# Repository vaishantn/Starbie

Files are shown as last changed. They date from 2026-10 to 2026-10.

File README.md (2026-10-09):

# Starbie ⭐

**Starbie** is a tiny, interactive motion-controlled digital pet—think of a custom-built, hardware-hackable desktop Tamagotchi! Designed from scratch as a custom PCB, Starbie brings a virtual pet to life using an embedded microcontroller, a crisp OLED display, environmental sensors, tilt detection, and tactile mechanical keyboard switches.

---

## 📑 Table of Contents
- [Features](#-features)
- [Bill of Materials (BOM)](#-bill-of-materials-bom)
- [Hardware Architecture & Pinout](#️-hardware-architecture--pinout)
- [Getting Started & Firmware](#-getting-started--firmware-installation)
- [Project Schematics](#-project-schematics)
- [Built With](#-built-with)

---

## 🌟 Features

* **Motion & Tilt Detection:** Integrated MPU6050 6-axis accelerometer and gyroscope to track orientation, shakes, and tilts so you can interact with your pet physically.
* **Environment Tracking:** Built-in DHT11 sensor to monitor ambient temperature and humidity.
* **Tactile Mechanical Input:** Uses genuine Cherry MX mechanical switches for satisfying tactile user control.
* **Crisp Visuals:** Features a 0.96-inch OLED graphic display capable of rendering smooth animations and expressions for your digital pet.
* **Compact Microcontroller Core:** Powered by the versatile Seeed Studio XIAO ESP32-C3 for low-power operation, Wi-Fi capabilities, and compact integration.

---

## 📦 Bill of Materials (BOM)

| Part Name | Qty | Description |
| :--- | :---: | :--- |
| **Seeed Studio XIAO ESP32-C3** | 1 | Low-power RISC-V microcontroller with Wi-Fi/BLE |
| **0.96" OLED Graphic Display** | 1 | Monochrome display module (I2C/SPI) for character rendering |
| **MPU6050 Sensor Module** | 1 | 3-axis accelerometer & 3-axis gyroscope |
| **Cherry MX Silent Red Switch** | 2 | Mechanical keyboard switches for user input buttons |
| **DHT11 Sensor** | 1 | Digital temperature and humidity sensor |
| **10k Resistor** | 1 | Pull-up resistor for sensor stability |

---

## 🛠️ Hardware Architecture & Pinout

Starbie's schematic routes all peripherals directly to the XIAO ESP32-C3 breakout headers:
* **I2C Bus:** Shared between the MPU6050 motion sensor and the 0.96" OLED display.
* **GPIO Inputs:** Connected to the Cherry MX mechanical switches with internal pull-ups enabled.
* **Single-Wire Interface:** Dedicated pin for reading temperature and humidity data from the DHT11 module.

---

## 🚀 Getting Started & Firmware Installation

### Prerequisites
* [Arduino IDE](https://www.arduino.cc/en/software) installed on your machine.
* ESP32 board support packages added via the Arduino Board Manager.
* Required libraries installed:
  * `Adafruit_GFX` & `Adafruit_SSD1306` (for the OLED display)
  * `Adafruit_MPU6050` (for motion tracking)
  * `DHT sensor library` (for environmental data)

### Flashing the Firmware
1. Clone this repository or download the source files.
2. Open the `starbie.ino` file inside the Arduino IDE.
3. Select your board (`Seeed Studio XIAO_ESP32C3`) and the correct COM port from **Tools > Board**.
4. Click the **Upload** button to flash the code to your microcontroller.

---

## 📸 Project Schematics

<p align="center">
  Schematic View
</p>

<p align="center">
  PCB Layout View
</p>

---

## 🧰 Built With

* **KiCad** - Schematic capture, custom footprint creation, and PCB layout routing
* **Arduino IDE / C++** - Firmware development and sensor integration

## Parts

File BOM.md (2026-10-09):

# Starbie – bill of materials

<!-- Generated by Half Life from project cmuxftd3k013u01p9ftee1w4r. Edits here are overwritten on the next sync. -->
<!-- Generated: 2026-10-09T22:37:54.580Z -->

> [!NOTE]
> This parts list is mirrored from [Half Life](https://halflife.hackclub.com). Editing it here will not change the platform's copy, and the next sync overwrites this file.

| Week | Tier | Parts funding |
| --- | --- | --- |
| Week 1 | Tier 1 | $30.00 |

| Part | What it's for | Qty | Unit | Total | Vendor |
| --- | --- | --- | --- | --- | --- |
| [Seeed Studio XIAO ESP32-C3 module](https://www.robotshop.com/products/seeedstudio-xiao-esp32c3-tiny-mcu-w-wi-fi-ble) | microcontroller for the board | 1 | $5.95 | $5.95 | [Robot Shop](https://www.robotshop.com/products/seeedstudio-xiao-esp32c3-tiny-mcu-w-wi-fi-ble) |
| [0.96" OLED Graphic Display 128x64](https://www.displaymodule.com/products/0-96-inch-oled-graphic-display-128x64-with-spi-i2c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) | To show the character | 1 | $4.90 | $4.90 | [Display Module](https://www.displaymodule.com/products/0-96-inch-oled-graphic-display-128x64-with-spi-i2c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) |
| [MPU6050](https://shillehtek.com/products/shillehtek-mpu-6050-module-gy-521-module-unsoldered-version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) | To detect motion and tilt | 1 | $6.99 | $6.99 | [ShillehTek](https://shillehtek.com/products/shillehtek-mpu-6050-module-gy-521-module-unsoldered-version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) |
| [Cherry MX Linear Switch](https://www.digikey.com/en/products/detail/cherry-americas-llc/MX2A-71NN/21738450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) | To interact with starbie | 2 | $1.95 | $3.90 | [Digikey](https://www.digikey.com/en/products/detail/cherry-americas-llc/MX2A-71NN/21738450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) |
| [DHT11 Temperature-Humidity Sensor](https://www.waveshare.com/temperature-humidity-sensor.htm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) | To check temperature and humidity | 1 | $3.99 | $3.99 | [Waveshare](https://www.waveshare.com/temperature-humidity-sensor.htm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) |
| [10k resistor](https://www.digikey.com/en/products/detail/yageo/CFR-25JB-52-10K/338) | pull up resistor for DHT11 sensor | 1 | $0.20 | $0.20 | [Digikey](https://www.digikey.com/en/products/detail/yageo/CFR-25JB-52-10K/338) |
| **Parts subtotal** | — | — | — | **$25.93** | — |
| **Tax & shipping** | — | — | — | **$0.00** | — |
| **Total** | — | — | — | **$25.93** | — |

$4.07 left of the tier's funding.

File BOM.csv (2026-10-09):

# Starbie bill of materials
Week | Tier | Parts funding
--- | --- | ---
Week 1 | Tier 1 | $30.00
Part | What it's for | Qty | Unit | Total | Vendor
--- | --- | --- | --- | --- | ---
[Seeed Studio XIAO ESP32-C3 module](https://www.seeedstudio.com/Seeed-XIAO-ESP32C3-p-5431.html) | microcontroller for the board | 1 | $4.99 | $4.99 | [Seeed Studio](https://www.seeedstudio.com/Seeed-XIAO-ESP32C3-p-5431.html)
[0.96 OLED Graphic Display 128x64](https://www.displaymodule.com/products/0-96-inch-oled-graphic-display-128x64-with-spi-i2c" | To show the character | 1 | $4.90 | $4.90 | [Display Module](https://www.displaymodule.com/products/0-96-inch-oled-graphic-display-128x64-with-spi-i2c
[MPU6050](https://shillehtek.com/products/shillehtek-mpu-6050-module-gy-521-module-unsoldered-version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 | To detect motion and tilt | 1 | $6.99 | $6.99 | [ShillehTek](https://shillehtek.com/products/shillehtek-mpu-6050-module-gy-521-module-unsoldered-version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
[Cherry MX Silent Red 45g Linear Switch](https://mechanicalkeyboards.com/products/cherry-mx-silent-red-45g-linear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 | To interact with starbie | 2 | $0.40 | $0.80 | [Mechanical Keyboards](https://mechanicalkeyboards.com/products/cherry-mx-silent-red-45g-linear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
[DHT11 Temperature-Humidity Sensor](https://www.waveshare.com/temperature-humidity-sensor.htm | To check temperature and humidity | 1 | $3.99 | $3.99 | [Waveshare](https://www.waveshare.com/temperature-humidity-sensor.htm
[10k resistor](https://www.digikey.com/en/products/detail/yageo/CFR-25JB-52-10K/338) | pull up resistor for DHT11 sensor | 1 | $0.20 | $0.20 | [Digikey](https://www.digikey.com/en/products/detail/yageo/CFR-25JB-52-10K/338)
**Parts subtotal** |  |  |  | $21.87
**Tax & shipping** |  |  |  | $0.00
**Total** |  |  |  | $21.87

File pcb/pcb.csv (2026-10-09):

Reference | Qty | Value | DNP | Exclude from BOM | Exclude from Board | Exclude from Simulation | Exclude from Position Files | Footprint | Datasheet
J1 | 1 | Conn_01x04_Pin |  |  |  |  | ${EXCLUDE_FROM_POS_FILES} | Imported Parts:Display_128x64_096_I2C
J2 | 1 | Conn_01x08_Pin |  |  |  |  | ${EXCLUDE_FROM_POS_FILES} | Connector_PinHeader_2.54mm:PinHeader_1x08_P2.54mm_Vertical
R1 | 1 | 10k |  |  |  |  | ${EXCLUDE_FROM_POS_FILES} | Resistor_THT:R_Axial_DIN0204_L3.6mm_D1.6mm_P7.62mm_Horizontal
SW1,SW2 | 2 | SW_Push |  |  |  |  | ${EXCLUDE_FROM_POS_FILES} | Button_Switch_Keyboard:SW_Cherry_MX_1.00u_PCB
U1 | 1 | XIAO-ESP32-C3-SMD |  |  |  |  | ${EXCLUDE_FROM_POS_FILES} | Seeed Studio XIAO Series Library:XIAO-ESP32-C3-SMD
U2 | 1 | DHT11 |  |  |  |  | ${EXCLUDE_FROM_POS_FILES} | Sensor:Aosong_DHT11_5.5x12.0_P2.54mm | http://akizukidenshi.com/download/ds/aosong/DHT11.pdf

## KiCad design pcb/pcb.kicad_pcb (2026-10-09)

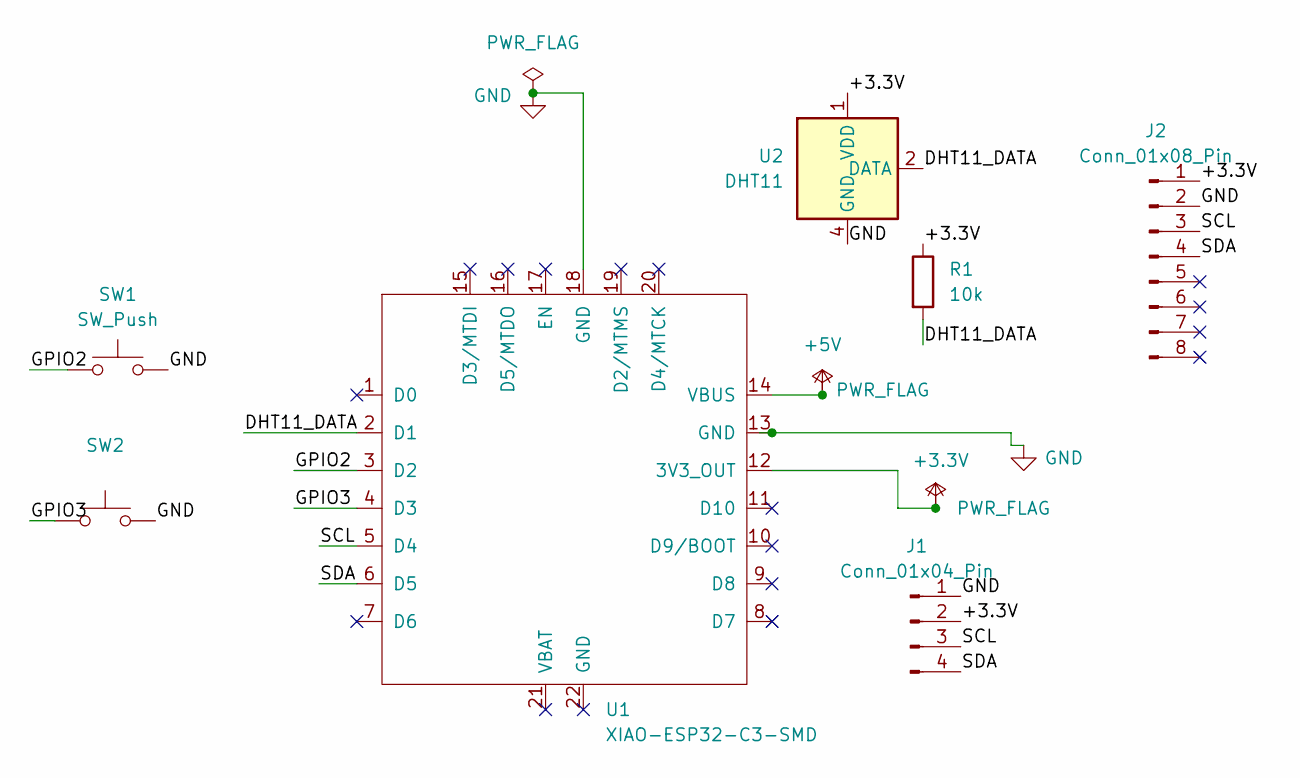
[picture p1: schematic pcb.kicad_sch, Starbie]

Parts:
J1: Conn_01x04_Pin; Display_128x64_096_I2C
J2: Conn_01x08_Pin; PinHeader_1x08_P2.54mm_Vertical
R1: 10k; R_Axial_DIN0204_L3.6mm_D1.6mm_P7.62mm_Horizontal
SW1, SW2: SW_Push; SW_Cherry_MX_1.00u_PCB
U1: XIAO-ESP32-C3-SMD
U2: DHT11; Aosong_DHT11_5.5x12.0_P2.54mm

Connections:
+3.3V: J1.2, J2.1, R1.1, U1.12 (3V3_OUT), U2.1 (VDD)
+5V: U1.14 (VBUS)
/DHT11_DATA: R1.2, U1.2 (D1), U2.2 (DATA)
/GPIO2: SW1.1, U1.3 (D2)
/GPIO3: SW2.1, U1.4 (D3)
/SCL: J1.3, J2.3, U1.5 (D4)
/SDA: J1.4, J2.4, U1.6 (D5)
GND: J1.1, J2.2, SW1.2, SW2.2, U1.13 (GND), U1.18 (GND), U2.4 (GND)

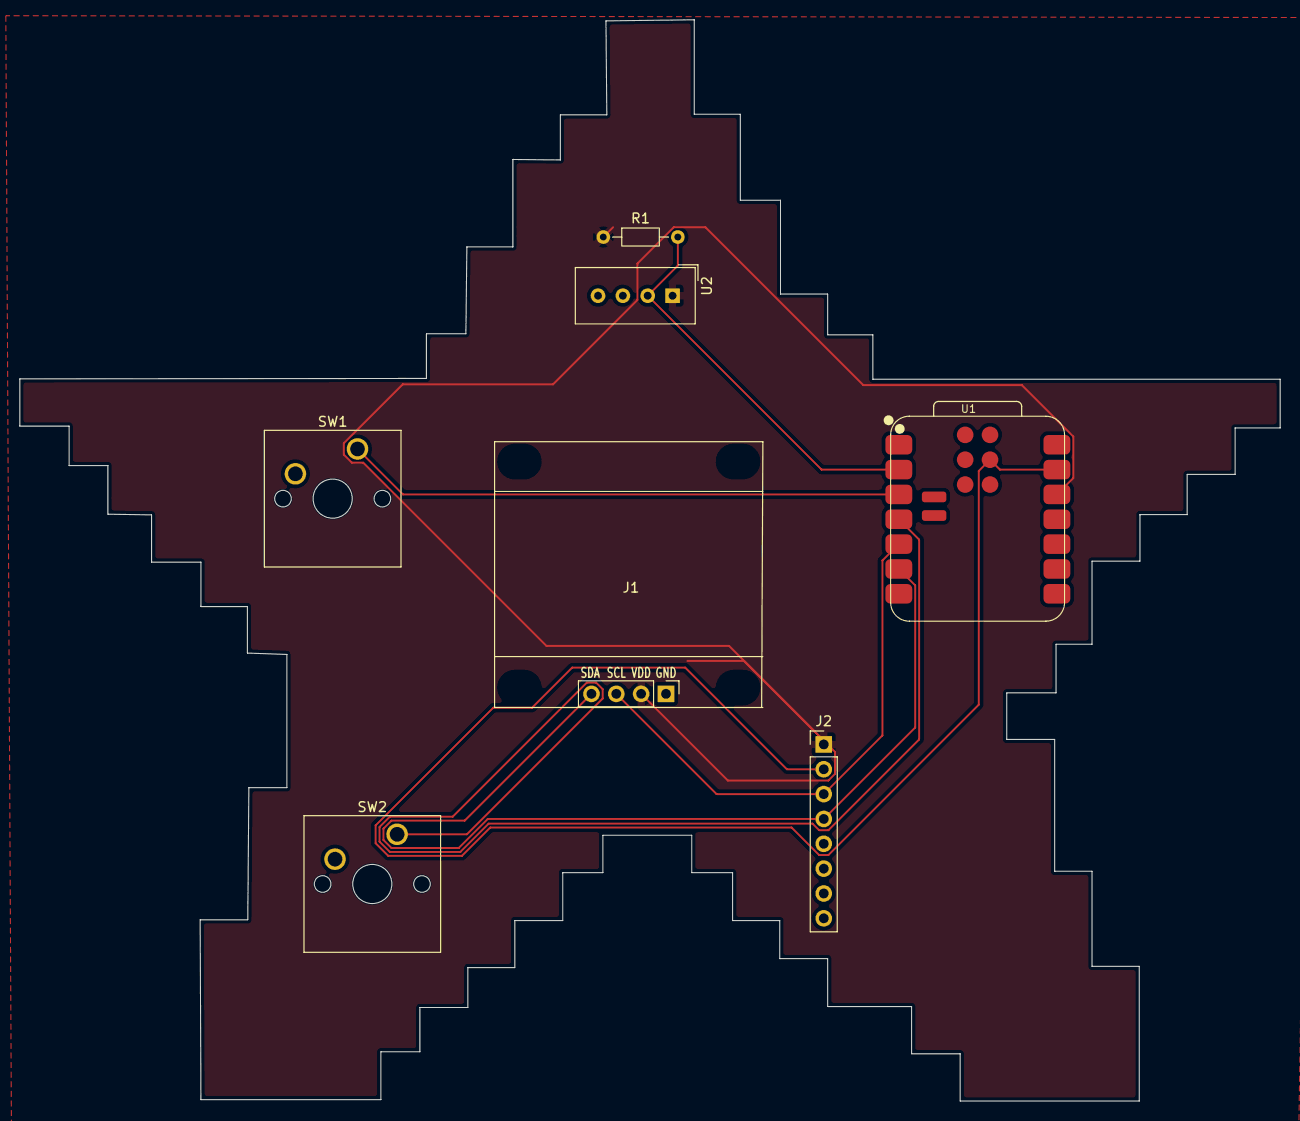
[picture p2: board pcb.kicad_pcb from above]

Board: 2 copper layers, 128.9 x 110.5 mm, 7 parts (0 on the bottom side), 7 nets.

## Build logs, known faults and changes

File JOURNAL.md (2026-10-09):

# Starbie – devlog

<!-- Generated by Half Life from project cmuxftd3k013u01p9ftee1w4r. Edits here are overwritten on the next sync. -->
<!-- Generated: 2026-10-09T22:26:31.207Z -->

> [!NOTE]
> This devlog is mirrored from [Half Life](https://halflife.hackclub.com). Editing it here will not change the platform's copy, and the next sync overwrites this file.

> A tiny motion-controlled digital pet, basically a desktop Tamagotchi. Totally not a Starboy.

| Week | Tier | Hours logged | Entries |
| --- | --- | --- | --- |
| Week 1 | Tier 1 | 11h | 8 |

## Contents

1. [2026-10-06 – Worked on the schematic in KiCad today! Grounded one side of the push button to GND and connected the signal pin directly to D0 on the XIAO ESP32-C3 for active-LOW input. Also wired up the power and g](#2026-10-06-worked-on-the-schematic-in-kicad-today-grounded-o)
2. [2026-10-07 – Finished drawing up the entire schematic in KiCad! All components are placed, connected, and verified. Next up is importing everything into the PCB editor to beautify the board layout—arranging the co](#2026-10-07-finished-drawing-up-the-entire-schematic-in-kicad)
3. [2026-10-08 – Today I continued cleaning up the schematic from yesterday. At first I thought I would just spend my time manually rerouting wires around the board to make it look neater. Instead, I learned how to us](#2026-10-08-today-i-continued-cleaning-up-the-schematic-from-)
4. [2026-10-08 – I started moving my finished schematic into the PCB layout! While I was doing this, I found a lot of errors because several of my parts didn't have the correct footprints assigned to them. I had to ch](#2026-10-08-i-started-moving-my-finished-schematic-into-the-p)
5. [2026-10-09 – I finished routing the pcb wiring. It took me so much time to get the custom boundary right because the first time it was too big, the second time it was too small, and the third time it was just righ](#2026-10-09-i-finished-routing-the-pcb-wiring-it-took-me-so-m)
6. [2026-10-09 – Spent this 2-hour session focusing on project documentation and component organization for Starbie. I put together a clear Bill of Materials (BOM) listing out all the necessary hardware like the micro](#2026-10-09-spent-this-2-hour-session-focusing-on-project-doc)
7. [2026-10-09 – Spent this 1-hour session cleaning up and refining the project repository for Starbie. I updated the README with comprehensive build details, organized all the exported Gerber (`.gbr`) layer files, jo](#2026-10-09-spent-this-1-hour-session-cleaning-up-and-refinin)
8. [2026-10-09 – Completely overhauled the project `README.md` for Starbie by introducing an intuitive Table of Contents, organizing a polished layout hierarchy, and refining both the Bill of Materials (BOM) and core](#2026-10-09-completely-overhauled-the-project-readmemd-for-st)

## Design

### 2026-10-06 – Worked on the schematic in KiCad today! Grounded one side of the push button to GND and connected the signal pin directly to D0 on the XIAO ESP32-C3 for active-LOW input. Also wired up the power and g

**1h**

Worked on the schematic in KiCad today! Grounded one side of the push button to GND and connected the signal pin directly to D0 on the XIAO ESP32-C3 for active-LOW input. Also wired up the power and ground paths across the component pins





### 2026-10-07 – Finished drawing up the entire schematic in KiCad! All components are placed, connected, and verified. Next up is importing everything into the PCB editor to beautify the board layout—arranging the co

**1h**

Finished drawing up the entire schematic in KiCad! All components are placed, connected, and verified. Next up is importing everything into the PCB editor to beautify the board layout—arranging the components neatly, adding custom graphics, and preparing for routing.





### 2026-10-08 – Today I continued cleaning up the schematic from yesterday. At first I thought I would just spend my time manually rerouting wires around the board to make it look neater. Instead, I learned how to us

**2h**

Today I continued cleaning up the schematic from yesterday. At first I thought I would just spend my time manually rerouting wires around the board to make it look neater. Instead, I learned how to use net labels to clean up the design. This makes the schematic look significantly more organized and much easier to read than having messy wires crossing each other all over the place!

This is before:


This is after:


### 2026-10-08 – I started moving my finished schematic into the PCB layout! While I was doing this, I found a lot of errors because several of my parts didn't have the correct footprints assigned to them. I had to ch

**1h**

I started moving my finished schematic into the PCB layout! While I was doing this, I found a lot of errors because several of my parts didn't have the correct footprints assigned to them. I had to check every part, figure out the errors, and assign the right footprints so everything would fit properly on the board.

From this:



To this:



### 2026-10-09 – I finished routing the pcb wiring. It took me so much time to get the custom boundary right because the first time it was too big, the second time it was too small, and the third time it was just righ

**3h**

I finished routing the pcb wiring. It took me so much time to get the custom boundary right because the first time it was too big, the second time it was too small, and the third time it was just right. Next I encountered a problem: I didn't assign the footprints correctly, so it took me time to fix it. Then the routing of wires took me time because I was trying to understand how to do it and I kept not having enough space, so I tweaked some copper zoning and now I have completed it.

Before:


After:




### 2026-10-09 – Spent this 2-hour session focusing on project documentation and component organization for Starbie. I put together a clear Bill of Materials (BOM) listing out all the necessary hardware like the micro

**2h**

Spent this 2-hour session focusing on project documentation and component organization for Starbie. I put together a clear Bill of Materials (BOM) listing out all the necessary hardware like the microcontroller, sensors, and mechanical switches, and to find the perfect vendor. I also wrote and refined the project README to properly document the build.

BOM:



Readme:





### 2026-10-09 – Spent this 1-hour session cleaning up and refining the project repository for Starbie. I updated the README with comprehensive build details, organized all the exported Gerber (`.gbr`) layer files, jo

**0.5h**

Spent this 1-hour session cleaning up and refining the project repository for Starbie. I updated the README with comprehensive build details, organized all the exported Gerber (`.gbr`) layer files, job files, and drill files (`.drl`) into a clean directory structure, and prepared everything for final production.

Added this to Readme:



Added gerbers:



### 2026-10-09 – Completely overhauled the project `README.md` for Starbie by introducing an intuitive Table of Contents, organizing a polished layout hierarchy, and refining both the Bill of Materials (BOM) and core

**0.5h**

Completely overhauled the project `README.md` for Starbie by introducing an intuitive Table of Contents, organizing a polished layout hierarchy, and refining both the Bill of Materials (BOM) and core feature sections to prep the custom PCB repo.







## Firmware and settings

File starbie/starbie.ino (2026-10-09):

#include <Wire.h>
#include <Adafruit_GFX.h>
#include <Adafruit_SSD1306.h>
#include <Adafruit_MPU6050.h>
#include <DHT.h>
#include <Preferences.h>
#include <math.h>

// =========================== BEGINNER SETTINGS ===========================
// Everything most builders will want to customize is in this one section.

// --- Your board's pins ----------------------------------------------------
// These are ESP32-C3 GPIO numbers, with the XIAO pin labels beside them.
const int I2C_SDA_PIN = 6;       // XIAO D4: OLED + MPU6050 SDA
const int I2C_SCL_PIN = 7;       // XIAO D5: OLED + MPU6050 SCL
const int DHT_PIN = 3;           // XIAO D1: DHT11 data
const int BUTTON_ONE_PIN = 4;    // XIAO D2: opens/confirms the radial menu
const int BUTTON_TWO_PIN = 5;    // XIAO D3: shows/hides stats

// Set this to false if your submission does not have a DHT11.
const bool USE_DHT11 = true;

// Most parts use these addresses. Only change them if an I2C scanner says
// your part is different (common OLED alternative: 0x3D).
const uint8_t OLED_ADDRESS = 0x3C;
const uint8_t MPU6050_ADDRESS = 0x68;

// --- Starting stats -------------------------------------------------------
// Stats are 0 to 100. They only change when you select an action or shake
// Starbie; nothing slowly drains while it sits on your desk.
const int STARTING_JOY = 70;
const int STARTING_ENERGY = 75;
const int STARTING_FULLNESS = 65;

// Set true, upload once, then set it back to false if you want a fresh pet.
const bool RESET_SAVED_PET_ON_BOOT = false;

// --- Radial menu ----------------------------------------------------------
// These four actions appear at TOP, RIGHT, BOTTOM, then LEFT in the menu.
// The last word controls the matching little visual reaction.
enum PetReaction {
  NAP_REACTION,
  JUMP_REACTION,
  HEART_REACTION,
  RUN_REACTION,
};

struct MenuItem {
  const char *label;
  int joyChange;
  int energyChange;
  int fullnessChange;
  PetReaction reaction;
};

const MenuItem MENU_ITEMS[] = {
  {"NAP",   1,  18, -4, NAP_REACTION},   // top: sleep and emit Zs
  {"PLAY", 12, -9, -5, RUN_REACTION},    // right: two fast laps + hearts
  {"FEED",  3,  2,  18, JUMP_REACTION},  // bottom: wiggle and jump
  {"PET",   7,  0,  0, HEART_REACTION},  // left: jump and emit hearts
};
const int MENU_ITEM_COUNT = sizeof(MENU_ITEMS) / sizeof(MENU_ITEMS[0]);

// --- Movement feel --------------------------------------------------------
// Bigger MENU_TILT_LIMIT makes the menu ball move less.
const float MENU_TILT_LIMIT = 6.0f;

// MPU6050 orientation: change these settings instead of rewiring your board.
// 1. If the sensor is turned 90 degrees, set SWAP_MPU_AXES to true.
// 2. If a direction feels backwards, change that direction from 1.0f to -1.0f.
const bool SWAP_MPU_AXES = false;
const float MENU_X_DIRECTION = 1.0f;
const float MENU_Y_DIRECTION = -1.0f;

// A small dead zone makes the ball rest in the center until the board is tilted.
const float MENU_CENTER_DEADZONE = 0.8f;
const float SHAKE_THRESHOLD = 7.0f;

// Shake is the only movement that has an effect outside the radial menu.
const int SHAKE_JOY_CHANGE = 5;
const int SHAKE_ENERGY_CHANGE = -2;
const int SHAKE_FULLNESS_CHANGE = -1;

// --- Your pet's bitmap and animation -------------------------------------
// This is a simplified 32 by 32, one-bit version of the supplied character.
// You can replace it with your own art later; keep these size values matched
// to the sprite array you paste in.
const int PET_SPRITE_WIDTH = 32;
const int PET_SPRITE_HEIGHT = 32;

// The pet wanders unless it is asleep. A non-nap action does a tiny shake,
// then a jump, except PLAY which runs two fast laps.
const uint16_t PET_WALK_PIXEL_MS = 70;
const uint16_t PET_PRE_JUMP_MS = 230;
const uint16_t PET_JUMP_MS = 430;
const int PET_JUMP_HEIGHT = 16;
const uint32_t NAP_DURATION_MS = 48000;  // 48 seconds: four times the old nap.
const uint16_t HEARTS_DURATION_MS = 1600;
const uint16_t PLAY_LAP_MS = 800;
const uint8_t PLAY_LAP_COUNT = 2;

// Each byte stores eight pixels, left to right. This sparse outline keeps the
// supplied creature readable on a tiny, one-bit OLED: head, eye, legs, tail,
// and a small flower-like ear accent all stay separate instead of becoming a blob.
const uint8_t PROGMEM PET_SPRITE[] = {
  0x00, 0x00, 0x00, 0x00,
  0x00, 0x00, 0x00, 0x00,
  0x00, 0x00, 0x00, 0x00,
  0x00, 0x00, 0x00, 0x00,
  0x00, 0x00, 0x00, 0x00,
  0x00, 0x00, 0x00, 0x00,
  0x00, 0x70, 0x0a, 0x00,
  0x00, 0xf8, 0x1f, 0x00,
  0x00, 0x8c, 0x3f, 0x80,
  0x00, 0x43, 0xff, 0x00,
  0x00, 0x43, 0xff, 0x00,
  0x00, 0x30, 0x7e, 0x00,
  0x00, 0x98, 0x01, 0x00,
  0x01, 0x98, 0x01, 0x80,
  0x03, 0x00, 0x10, 0xc0,
  0x03, 0x04, 0x00, 0xc0,
  0x01, 0x8b, 0x01, 0x80,
  0x01, 0xcb, 0x03, 0x80,
  0x03, 0xc0, 0x03, 0xc0,
  0x03, 0xc0, 0x03, 0xc0,
  0x01, 0xc0, 0x03, 0x80,
  0x01, 0x80, 0x01, 0x80,
  0x00, 0x60, 0x06, 0x00,
  0x00, 0x3f, 0xfc, 0x00,
  0x00, 0x7f, 0xfe, 0x00,
  0x00, 0x70, 0x0e, 0x00,
  0x00, 0x00, 0x00, 0x00,
  0x00, 0x00, 0x00, 0x00,
  0x00, 0x00, 0x00, 0x00,
  0x00, 0x00, 0x00, 0x00,
  0x00, 0x00, 0x00, 0x00,
  0x00, 0x00, 0x00, 0x00,
};
// ===========================================================================
// You can read below without needing to understand every line. The rest of
// the sketch handles buttons, sensors, drawing, and saving automatically.

const int SCREEN_WIDTH = 128;
const int SCREEN_HEIGHT = 64;
const int MENU_CENTER_X = 64;
const int MENU_CENTER_Y = 32;
const int MENU_ITEM_X[] = {64, 108, 64, 20};
const int MENU_ITEM_Y[] = {12, 32, 53, 32};
const int MENU_BALL_X_RANGE = 37;
const int MENU_BALL_Y_RANGE = 22;
const uint16_t BUTTON_DEBOUNCE_MS = 30;
const uint16_t MPU_READ_INTERVAL_MS = 30;
const uint16_t DHT_READ_INTERVAL_MS = 2200;
const uint16_t SHAKE_COOLDOWN_MS = 650;
const float STANDARD_GRAVITY = 9.80665f;

Adafruit_SSD1306 display(SCREEN_WIDTH, SCREEN_HEIGHT, &Wire, -1);
Adafruit_MPU6050 mpu;
DHT dht(DHT_PIN, DHT11);
Preferences preferences;

struct PetState {
  int joy;
  int energy;
  int fullness;
};

struct ButtonState {
  int pin;
  bool stableState;
  bool lastRawState;
  uint32_t lastChangedAt;
};

enum View {
  PET_VIEW,
  MENU_VIEW,
  STATS_VIEW,
};

PetState pet = {STARTING_JOY, STARTING_ENERGY, STARTING_FULLNESS};
ButtonState buttonOne = {BUTTON_ONE_PIN, HIGH, HIGH, 0};
ButtonState buttonTwo = {BUTTON_TWO_PIN, HIGH, HIGH, 0};
View currentView = PET_VIEW;

bool mpuFound = false;
bool dhtFound = false;
float accelerationX = 0.0f;
float accelerationY = 0.0f;
float accelerationZ = STANDARD_GRAVITY;
float temperatureC = NAN;
float humidity = NAN;
float menuBallX = MENU_CENTER_X;
float menuBallY = MENU_CENTER_Y;
float menuCenterAccelerationX = 0.0f;
float menuCenterAccelerationY = 0.0f;
int selectedMenuItem = -1;
uint32_t lastMpuReadAt = 0;
uint32_t lastDhtReadAt = 0;
uint32_t lastShakeAt = 0;
uint32_t shakeAnimationEndsAt = 0;
uint32_t petJumpStartedAt = 0;
uint32_t nappingUntil = 0;
uint32_t heartAnimationEndsAt = 0;
uint32_t playRunStartedAt = 0;
int nappingPetX = 0;

int petWalkingX(uint32_t now);

int keepInRange(int value, int smallest, int largest) {
  return constrain(value, smallest, largest);
}

void changePet(int joyChange, int energyChange, int fullnessChange) {
  pet.joy = keepInRange(pet.joy + joyChange, 0, 100);
  pet.energy = keepInRange(pet.energy + energyChange, 0, 100);
  pet.fullness = keepInRange(pet.fullness + fullnessChange, 0, 100);
}

void loadPet() {
  preferences.begin("starbie", false);
  if (RESET_SAVED_PET_ON_BOOT) {
    preferences.clear();
  }
  pet.joy = preferences.getInt("joy", STARTING_JOY);
  pet.energy = preferences.getInt("energy", STARTING_ENERGY);
  pet.fullness = preferences.getInt("full", STARTING_FULLNESS);
}

void savePet() {
  preferences.putInt("joy", pet.joy);
  preferences.putInt("energy", pet.energy);
  preferences.putInt("full", pet.fullness);
}

void setUpButton(ButtonState &button) {
  pinMode(button.pin, INPUT_PULLUP);
  button.stableState = digitalRead(button.pin);
  button.lastRawState = button.stableState;
  button.lastChangedAt = millis();
}

// Returns true exactly once for each press, even if the switch bounces.
bool wasPressed(ButtonState &button) {
  const bool rawState = digitalRead(button.pin);
  const uint32_t now = millis();

  if (rawState != button.lastRawState) {
    button.lastRawState = rawState;
    button.lastChangedAt = now;
  }

  if (rawState != button.stableState &&
      now - button.lastChangedAt >= BUTTON_DEBOUNCE_MS) {
    button.stableState = rawState;
    return button.stableState == LOW;
  }

  return false;
}

void updateMpu() {
  if (!mpuFound || millis() - lastMpuReadAt < MPU_READ_INTERVAL_MS) {
    return;
  }
  lastMpuReadAt = millis();

  sensors_event_t acceleration;
  sensors_event_t gyro;
  sensors_event_t sensorTemperature;
  mpu.getEvent(&acceleration, &gyro, &sensorTemperature);
  accelerationX = acceleration.acceleration.x;
  accelerationY = acceleration.acceleration.y;
  accelerationZ = acceleration.acceleration.z;
}

void updateDht() {
  if (!dhtFound || millis() - lastDhtReadAt < DHT_READ_INTERVAL_MS) {
    return;
  }
  lastDhtReadAt = millis();

  const float newHumidity = dht.readHumidity();
  const float newTemperatureC = dht.readTemperature();
  if (!isnan(newHumidity)) {
    humidity = newHumidity;
  }
  if (!isnan(newTemperatureC)) {
    temperatureC = newTemperatureC;
  }
}

int petWalkingX(uint32_t now) {
  const int farthestX = SCREEN_WIDTH - PET_SPRITE_WIDTH;
  const uint32_t roundTrip = static_cast<uint32_t>(farthestX) * 2;
  const uint32_t step = (now / PET_WALK_PIXEL_MS) % roundTrip;
  return step <= farthestX ? step : roundTrip - step;
}

uint32_t playRunDuration() {
  return static_cast<uint32_t>(PLAY_LAP_MS) * PLAY_LAP_COUNT;
}

bool isNapping() {
  return nappingUntil != 0 && millis() < nappingUntil;
}

bool isPlaying() {
  return playRunStartedAt != 0 && millis() - playRunStartedAt < playRunDuration();
}

int playRunX(uint32_t now) {
  const int farthestX = SCREEN_WIDTH - PET_SPRITE_WIDTH;
  const uint32_t lapAge = (now - playRunStartedAt) % PLAY_LAP_MS;
  const float progress = static_cast<float>(lapAge) / PLAY_LAP_MS;
  return progress < 0.5f ? static_cast<int>(progress * 2.0f * farthestX)
                         : static_cast<int>((1.0f - progress) * 2.0f * farthestX);
}

void updatePetTimers() {
  if (nappingUntil != 0 && !isNapping()) {
    nappingUntil = 0;  // The pet wakes naturally when its nap time is over.
  }
  if (playRunStartedAt != 0 && !isPlaying()) {
    playRunStartedAt = 0;  // PLAY is exactly two left-to-right-to-left laps.
  }
}

// While the menu is open, the MPU6050 acts like a tiny air mouse. The position
// at the instant Button 1 opens the menu becomes the center for that menu use.
void updateMenuBall() {
  float xTilt = accelerationX - menuCenterAccelerationX;
  float yTilt = accelerationY - menuCenterAccelerationY;

  if (SWAP_MPU_AXES) {
    const float oldXTilt = xTilt;
    xTilt = yTilt;
    yTilt = oldXTilt;
  }
  xTilt = constrain(xTilt * MENU_X_DIRECTION, -MENU_TILT_LIMIT, MENU_TILT_LIMIT);
  yTilt = constrain(yTilt * MENU_Y_DIRECTION, -MENU_TILT_LIMIT, MENU_TILT_LIMIT);
  const float targetX = MENU_CENTER_X + (xTilt / MENU_TILT_LIMIT) * MENU_BALL_X_RANGE;
  const float targetY = MENU_CENTER_Y + (yTilt / MENU_TILT_LIMIT) * MENU_BALL_Y_RANGE;

  // This small amount of smoothing makes the ball feel less jittery.
  menuBallX += (targetX - menuBallX) * 0.20f;
  menuBallY += (targetY - menuBallY) * 0.20f;

  // The menu has four full sectors, not four tiny targets. Any tilt direction
  // past the center dead zone selects its matching top/right/bottom/left action.
  if (fabsf(xTilt) < MENU_CENTER_DEADZONE && fabsf(yTilt) < MENU_CENTER_DEADZONE) {
    selectedMenuItem = -1;
  } else if (fabsf(xTilt) > fabsf(yTilt)) {
    selectedMenuItem = xTilt > 0.0f ? 1 : 3;  // right or left
  } else {
    selectedMenuItem = yTilt > 0.0f ? 2 : 0;  // bottom or top
  }
}

void checkForShake() {
  if (!mpuFound || currentView != PET_VIEW) {
    return;
  }

  const float magnitude = sqrtf(accelerationX * accelerationX +
                                accelerationY * accelerationY +
                                accelerationZ * accelerationZ);
  const uint32_t now = millis();
  if (fabsf(magnitude - STANDARD_GRAVITY) >= SHAKE_THRESHOLD &&
      now - lastShakeAt >= SHAKE_COOLDOWN_MS) {
    lastShakeAt = now;
    nappingUntil = 0;  // A shake wakes a sleeping pet right away.
    shakeAnimationEndsAt = now + 350;
    changePet(SHAKE_JOY_CHANGE, SHAKE_ENERGY_CHANGE, SHAKE_FULLNESS_CHANGE);
    savePet();
  }
}

void openMenu() {
  currentView = MENU_VIEW;
  selectedMenuItem = -1;
  menuBallX = MENU_CENTER_X;
  menuBallY = MENU_CENTER_Y;
  // Calibrate here so every menu starts from however the builder is holding it.
  menuCenterAccelerationX = accelerationX;
  menuCenterAccelerationY = accelerationY;
}

void chooseMenuItem() {
  if (selectedMenuItem == -1) {
    return;  // Keep the menu open until the ball reaches a choice.
  }

  const MenuItem &item = MENU_ITEMS[selectedMenuItem];
  changePet(item.joyChange, item.energyChange, item.fullnessChange);
  savePet();
  const uint32_t now = millis();
  nappingUntil = 0;
  heartAnimationEndsAt = 0;
  playRunStartedAt = 0;

  if (item.reaction == NAP_REACTION) {
    petJumpStartedAt = 0;
    nappingPetX = petWalkingX(now);
    nappingUntil = now + NAP_DURATION_MS;
  } else if (item.reaction == RUN_REACTION) {
    petJumpStartedAt = 0;
    playRunStartedAt = now;
    heartAnimationEndsAt = now + playRunDuration();
  } else {
    // A confirmed action gets a little anticipation shake before the jump.
    petJumpStartedAt = now;
    if (item.reaction == HEART_REACTION) {
      heartAnimationEndsAt = now + HEARTS_DURATION_MS;
    }
  }
  currentView = PET_VIEW;
}

void handleButtons() {
  if (wasPressed(buttonOne)) {
    if (currentView == MENU_VIEW) {
      chooseMenuItem();
    } else {
      openMenu();
    }
  }

  if (wasPressed(buttonTwo)) {
    // Button 2 never changes the pet. It only lets you peek at the values.
    currentView = currentView == STATS_VIEW ? PET_VIEW : STATS_VIEW;
  }
}

void drawHeart(int x, int y) {
  // A tiny seven-pixel-wide heart that stays crisp on the OLED.
  display.fillRect(x - 2, y, 2, 2, SSD1306_WHITE);
  display.fillRect(x + 1, y, 2, 2, SSD1306_WHITE);
  display.fillRect(x - 3, y + 2, 7, 2, SSD1306_WHITE);
  display.fillRect(x - 2, y + 4, 5, 1, SSD1306_WHITE);
  display.fillRect(x - 1, y + 5, 3, 1, SSD1306_WHITE);
  display.drawPixel(x, y + 6, SSD1306_WHITE);
}

void drawHearts(uint32_t now, int petX, int petY) {
  if (now >= heartAnimationEndsAt) {
    return;
  }

  const float progress =
      1.0f - static_cast<float>(heartAnimationEndsAt - now) / HEARTS_DURATION_MS;
  const int rise = static_cast<int>(progress * 18.0f);
  drawHeart(petX + 10, petY - 3 - rise);
  drawHeart(petX + 22, petY - 9 - rise / 2);
}

void drawSleepZs(uint32_t now, int petX, int petY) {
  // The Zs float upward, then loop back down while the pet is napping.
  const int rise = static_cast<int>((now / 300UL) % 15UL);
  display.setTextSize(1);
  display.setTextColor(SSD1306_WHITE);
  display.setCursor(petX + 23, petY - 2 - rise);
  display.print("z");
  display.setCursor(petX + 28, petY - 8 - rise / 2);
  display.print("z");
}

void drawPet() {
  display.clearDisplay();

  const uint32_t now = millis();
  int petX = isNapping() ? nappingPetX : petWalkingX(now);
  if (isPlaying()) {
    petX = playRunX(now);
  }
  int petY = SCREEN_HEIGHT - PET_SPRITE_HEIGHT;

  // The pet always wanders except during a nap; PLAY temporarily takes over.
  if (now < shakeAnimationEndsAt) {
    petX += static_cast<int>(sinf(now / 18.0f) * 3.0f);
  }

  if (!isNapping() && petJumpStartedAt != 0) {
    const uint32_t animationAge = now - petJumpStartedAt;

    if (animationAge < PET_PRE_JUMP_MS) {
      petX += static_cast<int>(sinf(now / 16.0f) * 3.0f);
    } else if (animationAge < PET_PRE_JUMP_MS + PET_JUMP_MS) {
      const float jumpProgress =
          static_cast<float>(animationAge - PET_PRE_JUMP_MS) / PET_JUMP_MS;
      petY -= static_cast<int>(sinf(jumpProgress * PI) * PET_JUMP_HEIGHT);
    } else {
      petJumpStartedAt = 0;
    }
  }

  petX = constrain(petX, 0, SCREEN_WIDTH - PET_SPRITE_WIDTH);
  display.drawBitmap(petX, petY, PET_SPRITE, PET_SPRITE_WIDTH, PET_SPRITE_HEIGHT,
                     SSD1306_WHITE);

  if (isNapping()) {
    drawSleepZs(now, petX, petY);
  }
  drawHearts(now, petX, petY);
}

void drawMenuItem(int item) {
  const int boxWidth = 33;
  const int boxHeight = 12;
  const int boxX = MENU_ITEM_X[item] - boxWidth / 2;
  const int boxY = MENU_ITEM_Y[item] - boxHeight / 2;
  const bool isSelected = item == selectedMenuItem;

  if (isSelected) {
    display.fillRoundRect(boxX, boxY, boxWidth, boxHeight, 3, SSD1306_WHITE);
    display.setTextColor(SSD1306_BLACK);
  } else {
    display.drawRoundRect(boxX, boxY, boxWidth, boxHeight, 3, SSD1306_WHITE);
    display.setTextColor(SSD1306_WHITE);
  }

  display.setTextSize(1);
  const int labelLength = strlen(MENU_ITEMS[item].label);
  display.setCursor(MENU_ITEM_X[item] - labelLength * 3, MENU_ITEM_Y[item] - 3);
  display.print(MENU_ITEMS[item].label);
  display.setTextColor(SSD1306_WHITE);
}

void drawMenu() {
  display.clearDisplay();
  // The two diagonal lines divide the screen into four big selection sectors.
  display.drawLine(0, 0, SCREEN_WIDTH - 1, SCREEN_HEIGHT - 1, SSD1306_WHITE);
  display.drawLine(0, SCREEN_HEIGHT - 1, SCREEN_WIDTH - 1, 0, SSD1306_WHITE);
  for (int item = 0; item < MENU_ITEM_COUNT; item++) {
    drawMenuItem(item);
  }

  display.drawCircle(MENU_CENTER_X, MENU_CENTER_Y, 11, SSD1306_WHITE);
  display.fillCircle(static_cast<int>(menuBallX), static_cast<int>(menuBallY), 4,
                     SSD1306_WHITE);
}

void drawStatBar(int y, const char *label, int value) {
  display.setTextSize(1);
  display.setTextColor(SSD1306_WHITE);
  display.setCursor(4, y);
  display.print(label);
  display.drawRect(48, y, 57, 8, SSD1306_WHITE);
  display.fillRect(49, y + 1, map(value, 0, 100, 0, 55), 6, SSD1306_WHITE);
  display.setCursor(109, y);
  display.print(value);
}

void drawStats() {
  display.clearDisplay();
  drawStatBar(5, "JOY", pet.joy);
  drawStatBar(20, "ENERGY", pet.energy);
  drawStatBar(35, "FULL", pet.fullness);

  display.setCursor(4, 53);
  if (!isnan(temperatureC)) {
    display.print("TEMP ");
    display.print(static_cast<int>(temperatureC));
    display.print("C");
  } else {
    display.print("TEMP --");
  }

  display.setCursor(76, 53);
  if (!isnan(humidity)) {
    display.print("H ");
    display.print(static_cast<int>(humidity));
    display.print("%");
  } else {
    display.print("H --");
  }
}

void drawCurrentView() {
  if (currentView == MENU_VIEW) {
    drawMenu();
  } else if (currentView == STATS_VIEW) {
    drawStats();
  } else {
    drawPet();
  }
  display.display();
}

void setup() {
  Serial.begin(115200);
  Wire.begin(I2C_SDA_PIN, I2C_SCL_PIN);
  setUpButton(buttonOne);
  setUpButton(buttonTwo);
  loadPet();

  if (!display.begin(SSD1306_SWITCHCAPVCC, OLED_ADDRESS)) {
    Serial.println("OLED not found. Check power, GND, SDA, SCL, and address.");
    while (true) {
      delay(10);
    }
  }

  mpuFound = mpu.begin(MPU6050_ADDRESS, &Wire);
  if (mpuFound) {
    mpu.setAccelerometerRange(MPU6050_RANGE_8_G);
    mpu.setGyroRange(MPU6050_RANGE_500_DEG);
    mpu.setFilterBandwidth(MPU6050_BAND_21_HZ);
  } else {
    Serial.println("MPU6050 not found. The menu will not move until it is connected.");
  }

  if (USE_DHT11) {
    dht.begin();
    dhtFound = true;
  }

  drawCurrentView();
}

void loop() {
  updateMpu();
  updateDht();
  updatePetTimers();
  handleButtons();

  if (currentView == MENU_VIEW) {
    updateMenuBall();
  } else {
    checkForShake();
  }

  drawCurrentView();
  delay(16);  // Smooth display updates without making the code complicated.
}

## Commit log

2026-10-09 Initialize README with project details
    Added detailed project description, features, BOM, and tools used.
2026-10-09 Update README with project schematics
    Removed project preview section and added project schematics images.
2026-10-09 Revise README with project details and instructions
    Enhanced the README with detailed project features, BOM, hardware architecture, and firmware installation instructions.
2026-10-09 Rename Project Preview to Project Schematics
    Updated project section to include schematics images.
2026-10-09 Fix formatting in README for Arduino IDE section
2026-10-18 Swap I2C SDA and SCL pin assignments
2026-10-18 Simplify README introduction and remove sections
    Condensed the introduction and removed detailed features and BOM sections.
2026-10-19 Revise README with features and BOM section
    Updated features and project details in README.
